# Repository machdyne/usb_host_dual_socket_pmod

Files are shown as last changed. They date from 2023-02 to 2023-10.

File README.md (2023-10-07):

# USB Host Dual Socket Pmod™ Compatible Module

This PMOD is designed for implementing USB host mode directly in an FPGA. It contains the necessary resistors as well as a boost converter to supply 5V to the USB VBUS.

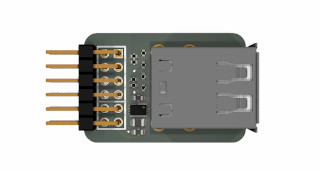
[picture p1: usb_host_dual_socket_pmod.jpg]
USB Host Dual Socket PMOD


This repo contains PCB layouts, schematics and pinouts.

Find more information on the [product page](https://machdyne.com/product/usb-host-dual-socket-pmod/).

## Pinout

| Pin | Signal |
| --- | --- |
| 1 | USB2\_DP (bottom socket) |
| 2 | USB2\_DN (bottom socket) |
| 3 | USB1\_DP (top socket) |
| 4 | USB1\_DN (top socket)  |
| 5 | GND |
| 6 | 3V3|
| 7 | NC |
| 8 | NC |
| 9 | NC |
| 10 | NC |
| 11 | GND |
| 12 | 3V3|

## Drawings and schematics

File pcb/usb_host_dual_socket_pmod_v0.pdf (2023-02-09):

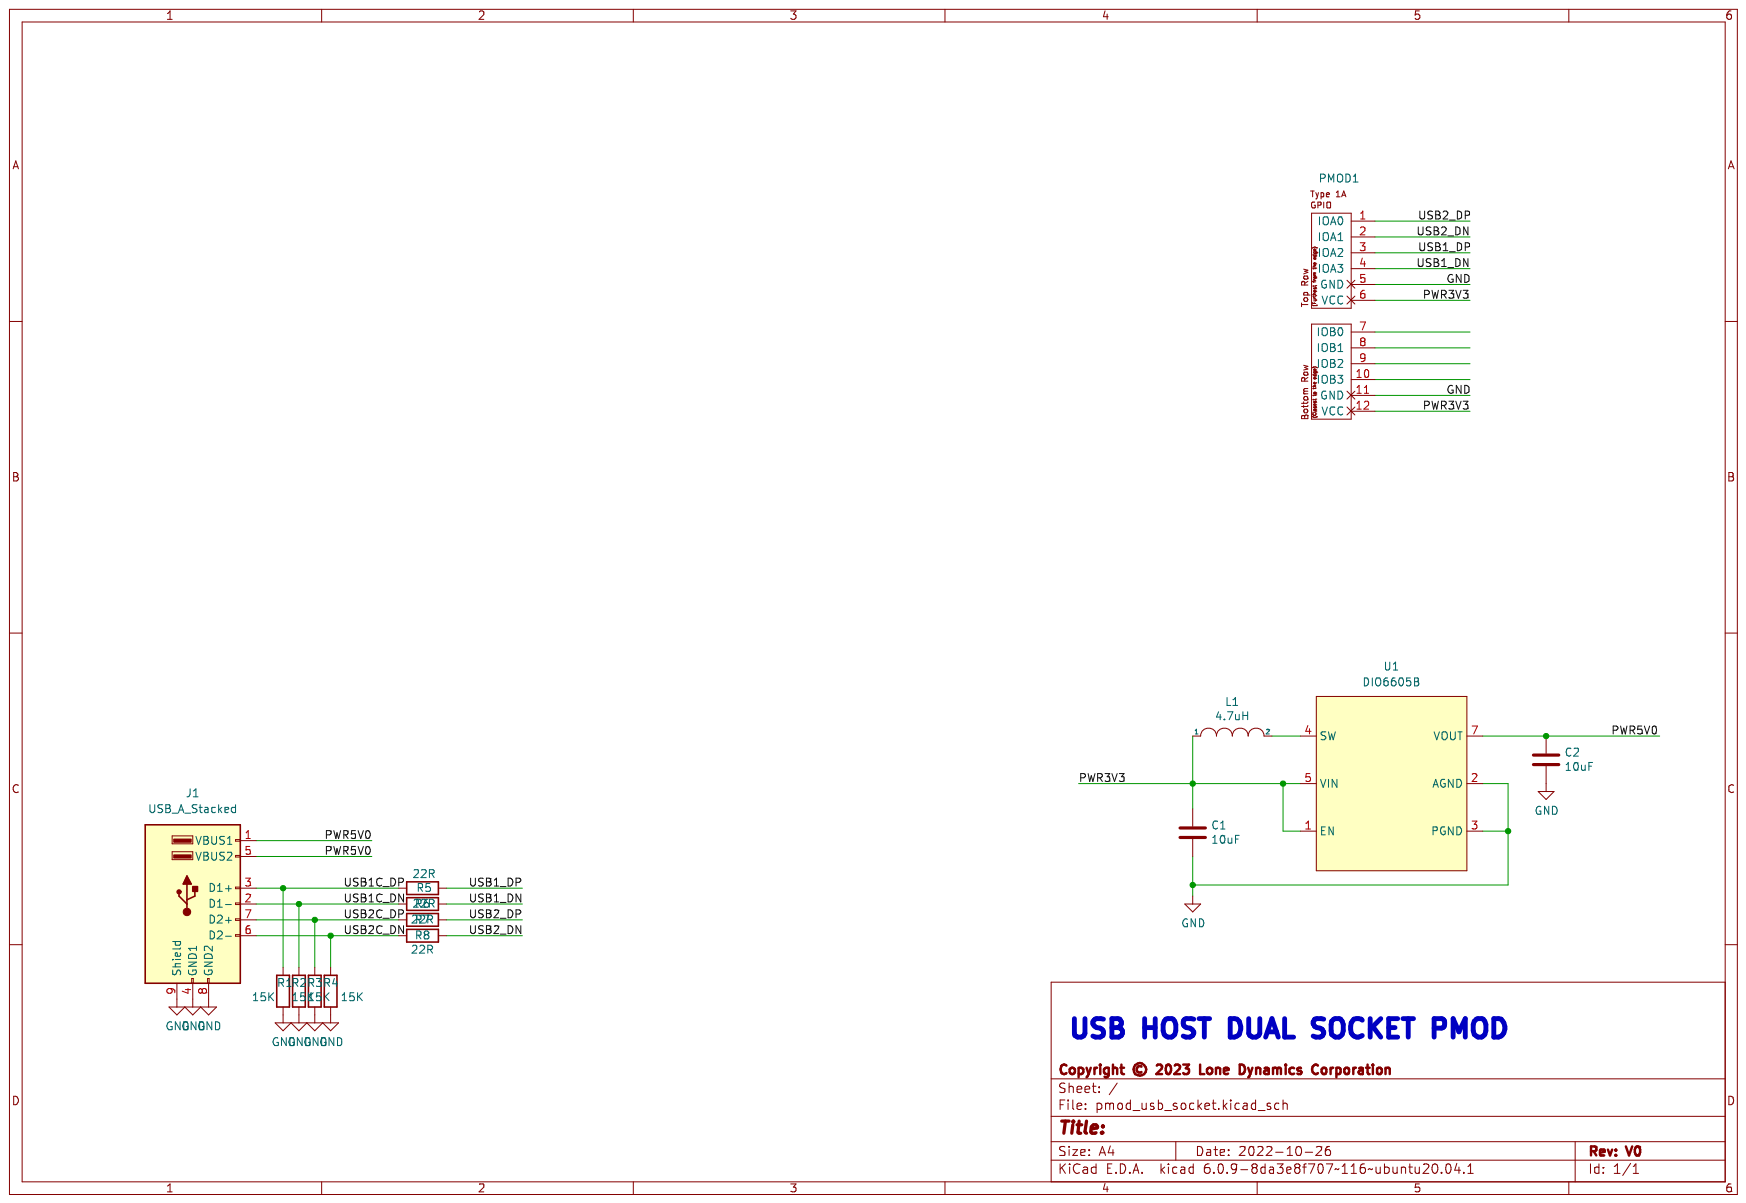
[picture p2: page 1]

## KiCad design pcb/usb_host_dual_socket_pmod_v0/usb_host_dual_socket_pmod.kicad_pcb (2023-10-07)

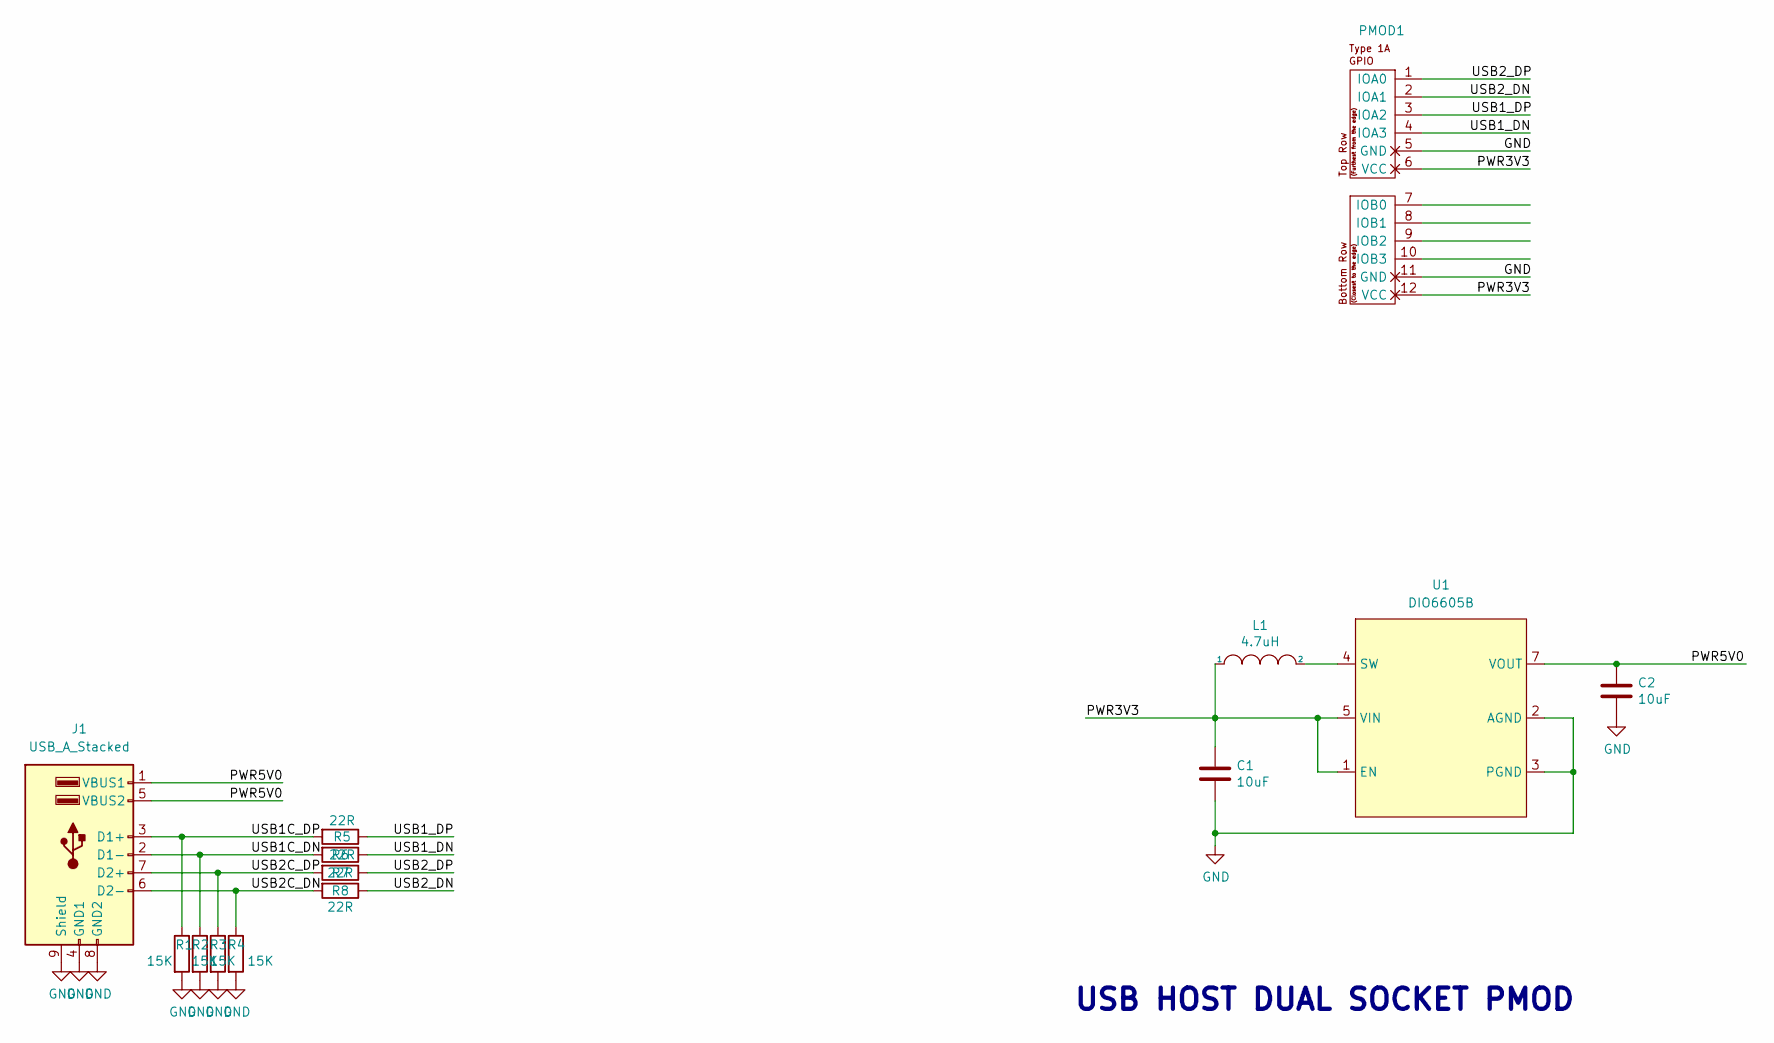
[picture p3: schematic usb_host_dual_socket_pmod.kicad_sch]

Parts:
C1, C2: 10uF; L_0603_1608Metric
J1: USB_A_Stacked; USB_A_Wuerth_61400826021_Horizontal_Stacked
L1: 4.7uH; L_0805_2012Metric
PMOD1: PMOD-Device-x2-Type-1A-GPIO; pmod_pin_array_6x2
R1, R2, R3, R4: 15K; R_0402_1005Metric
R5, R6, R7, R8: 22R; R_0402_1005Metric
U1: DIO6605B; TDFN-8-1EP_3x2mm_P0.5mm_EP1.4x1.4mm

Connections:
/PWR3V3: C1.1, L1.1, PMOD1.6 (VCC), PMOD1.12 (VCC), U1.1 (EN), U1.5 (VIN)
/PWR5V0: C2.1, J1.1 (VBUS1), J1.5 (VBUS2), U1.7 (VOUT)
/USB1C_DN: J1.2 (D1-), R2.1, R6.2
/USB1C_DP: J1.3 (D1+), R1.1, R5.2
/USB1_DN: PMOD1.4 (IOA3), R6.1
/USB1_DP: PMOD1.3 (IOA2), R5.1
/USB2C_DN: J1.6 (D2-), R4.1, R8.2
/USB2C_DP: J1.7 (D2+), R3.1, R7.2
/USB2_DN: PMOD1.2 (IOA1), R8.1
/USB2_DP: PMOD1.1 (IOA0), R7.1
GND: C1.2, C2.2, J1.4 (GND1), J1.8 (GND2), J1.9 (Shield), PMOD1.5 (GND), PMOD1.11 (GND), R1.2, R2.2, R3.2, R4.2, U1.2 (AGND), U1.3 (PGND)
unnamed: L1.2, U1.4 (SW)

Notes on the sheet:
USB HOST DUAL SOCKET PMOD

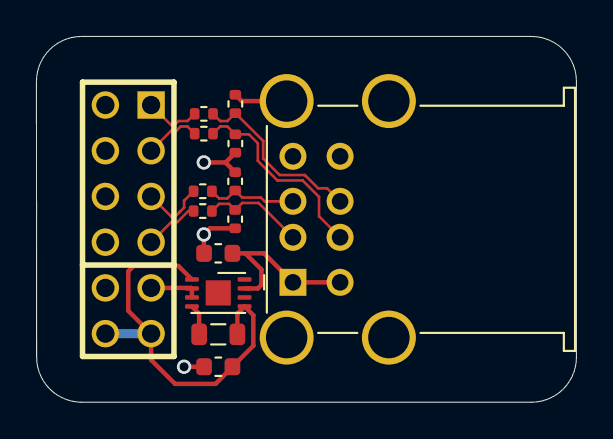
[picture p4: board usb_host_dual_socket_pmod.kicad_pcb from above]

Board: 2 copper layers, 30.0 x 20.3 mm, 14 parts (0 on the bottom side), 12 nets.

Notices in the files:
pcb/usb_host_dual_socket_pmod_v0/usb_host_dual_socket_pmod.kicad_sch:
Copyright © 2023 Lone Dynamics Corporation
